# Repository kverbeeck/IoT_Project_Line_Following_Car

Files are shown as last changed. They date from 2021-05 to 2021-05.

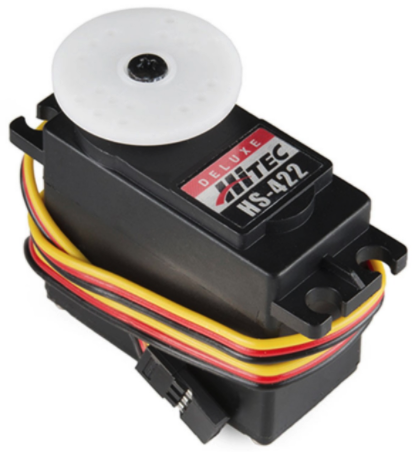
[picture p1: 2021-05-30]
Photos/New Design/Screen Shot 2021-05-30 at 12.21.13.png

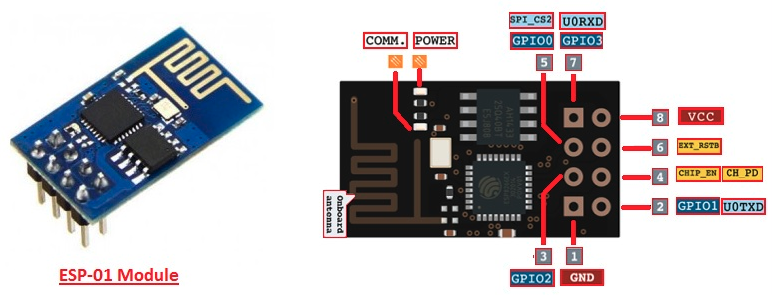
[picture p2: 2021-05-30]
Photos/New Design/Screen Shot 2021-05-30 at 12.37.02.png

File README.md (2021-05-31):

# IoT_Project_Self_Driving_Car

YouTube Video - Evaluation Week 5:  https://www.youtube.com/watch?v=Afq3bGS6EhM
YouTube Video - Evaluation Week 3: https://www.youtube.com/watch?v=AkNlcWbXoIE

## Description Assignment

Mercedes-Benz wants to automate its museum in Stuttgart. To do this, they want a system, which will allow a visitor to take a seat in a self-driving car. At the beginning of the tour, the visitor can take place in one of these cars that will drive around the entire museum. At the end, the visitor gets out and the trolley returns to the beginning of the tour so that new visitors can embark.

The route that the cars have to follow is fixed with a white tape on the floor, which makes it possible to adapt the tour if new exhibits are added. At each exhibit, a transverse white line will cross the tour line, this way the car knows where a museum piece is exhibited and that it has to stop. If the driver wants to continue, he or she can press a push-button inside the car and the tour will continue to the next exhibited item. 

To avoid congestion, the car will automatically continue the tour after 5 minutes.
Optionally, they also want to operate the cars remotely, for which the Control Center could take over the function of the push-button with an app.

Of course it is also important that the cars do not collide, therefore there should always be a minimum distance of 1.5 meters between the trolleys (Corona measures). If a car detects that it is too close to the one in front, it must stop and only continue if the one in front also continues to drive.

The cars are also equipped with LEDs. Using this signalization, the staff present in the control room can check cameras should there be a problem. 
•	A green LED will light up if there are no issues.
•	A red LED will light up if the car has lost track of the white line.
•	A orange LED will light up if the car detects an obstacle (other car or anything else in its path).

## Requirements:
•	The car can autonomously follow a track indicated by a white line.
•	The car must stop at a white line and can only continue driving if:
o	The driver pushes the drive-through push-button.
o	The trolley has been stationary for 5 minutes.
o	Optional: when the control center activates the car with their custom made application.
•	The cars must not collide.
o	If a car is halted, the cars behind it will keep their distance and only continue their route when the car in front of them continues its path.
•	Should there occurre problems with a car, it will be forced to stop and inform the control center by means of LEDs mounted on the cars.
o	Signalization in case of problems:
	Green LED: No issues.
	Orange LED: Obstacle (other car or anything else in its path).
	Red led: car has lost track of the white line.

## What does Mercedes-Benz expect
•	A brief description of the used hardware.
o	Files to produce the enclosure.
o	Electronic components.
o	Schematics and PCB (if applicable).
•	Documented code.
•	Brief description of to produce these cars themselves.
o	Tutorial.
All of this will be provided to them through a GitHub page.

## Follow-up:
Mercedes-Benz wants to take the cars into production after 7 weeks, there will be 3 evaluations.

In 3 weeks time the car should be driving and have basic functionality (line following). 

In 5 weeks they want to be sure that the cars have the correct functions to :
•	Follow the white line.
•	Stop and continue at each transverse white line.
•	Signalization.
In 7 weeks a working prototype should be presented. This prototype will be tested for functionality and speed. The prototype may not contain any loose components, so the use of a breadboard is not allowed. At this time, all documentation should also have been provided.

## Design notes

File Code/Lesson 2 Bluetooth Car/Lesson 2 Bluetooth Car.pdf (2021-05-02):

Http://www.elegoo.com

Tips: If you have any questions or run into any problems during assembling and testing Smart Robot Car please feel free to contact us at service@elegoo.com or euservice@elegoo.com (Europe customers).

# Lesson 2 Bluetooth Car

### Points of This Section

It is very important and so cool to control your car wirelessly in a certain space when we learn the Arduino. So in this lesson, we will teach you how to control a car by Bluetooth. Learning Objectives:

Learn how to use the Bluetooth module and the Bluetooth APP Learn how to control the light by using Bluetooth
Learn how to control the vehicle via Bluetooth

Preparations:
A vehicle (equipped with battery)
A USB cable
A Bluetooth module
A Phone or tablet

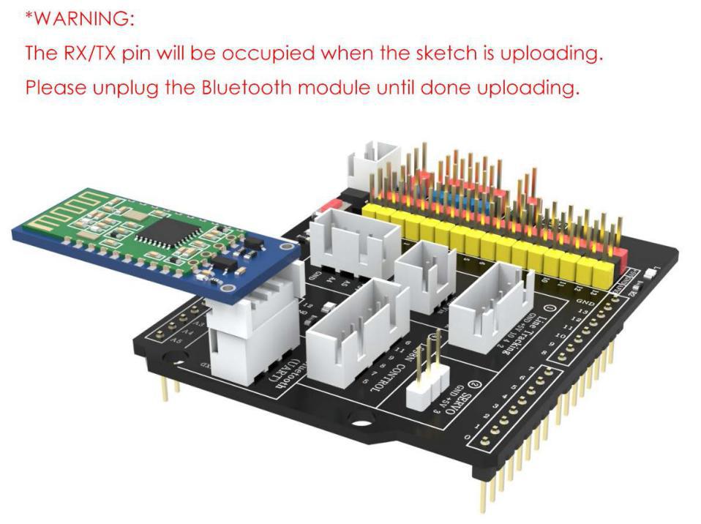
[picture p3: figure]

Tips: If you have any questions or run into any problems during assembling and testing Smart Robot Car please feel free to contact us at service@elegoo.com or euservice@elegoo.com (Europe customers).

# Ⅰ. Bluetooth module (BT16 4.2)

The Bluetooth is a wireless technology standard for exchanging data between fixed and mobile devices over short distances using short-wave UHF radio waves in the industrial, scientific, and medical radio bands (2.400 to 2.485 GHz), and building personal area networks (PANs). There are also RF protocols such as ZigBee and Wi-Fi.

In Smart Car Kit, we use the Bluetooth module model "DX-BT16", it can send serial data to other devices via Bluetooth.

DX-BT16 communicates with UNO through the RX/TX pin on the shield.

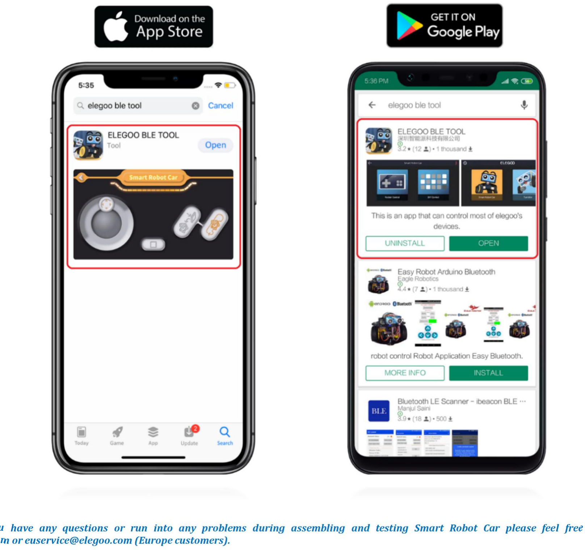
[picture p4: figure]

Tips: If you have any questions or run into any problems during assembling and testing Smart Robot Car please feel free to contact us at service@elegoo.com or euservice@elegoo.com (Europe customers).

## Ⅱ. Getting Started with the ELEGOO BLE Tool APP

Before beginning, connect the DX-BT16 4.2 Bluetooth module to the expansion board and turn on the

## power. STEP1: Install the application

For Android
There are two ways to install the Android application. 1. For Android system, copy the APK file to the Android products devices and install it. The APK file located in "Elegoo Smart Robot Car Kit V3.0_plus \ ELEGOO BLE Tool.apk" 2. Search “ELEGOO BLE Tool” in Google Play Store and install it. For IOS

Search “ELEGOO BLE Tool” in Apple APP Store and install it.

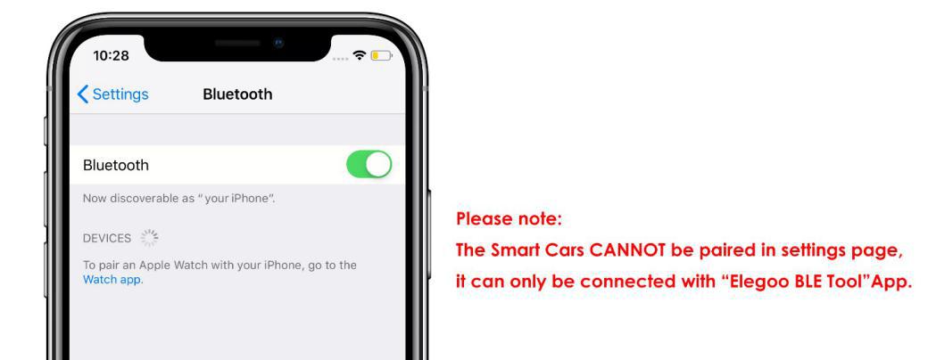
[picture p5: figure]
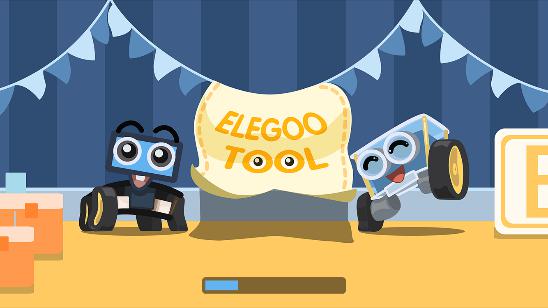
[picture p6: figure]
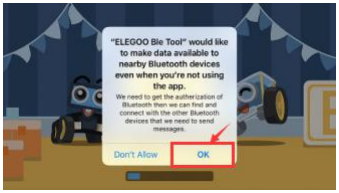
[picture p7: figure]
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

## STEP2: Open the APP

As below, we use an iPhone for example to show you how to control the Elegoo Smart Robot Car via this App:

First of all, turn on your cellphone’s Bluetooth function.

Open the “Elegoo BLE Tool” App.

Click OK (Please click OK when the App requests for the location permission, otherwise it will affect the Bluetooth function.)

## STEP3: Choose the language

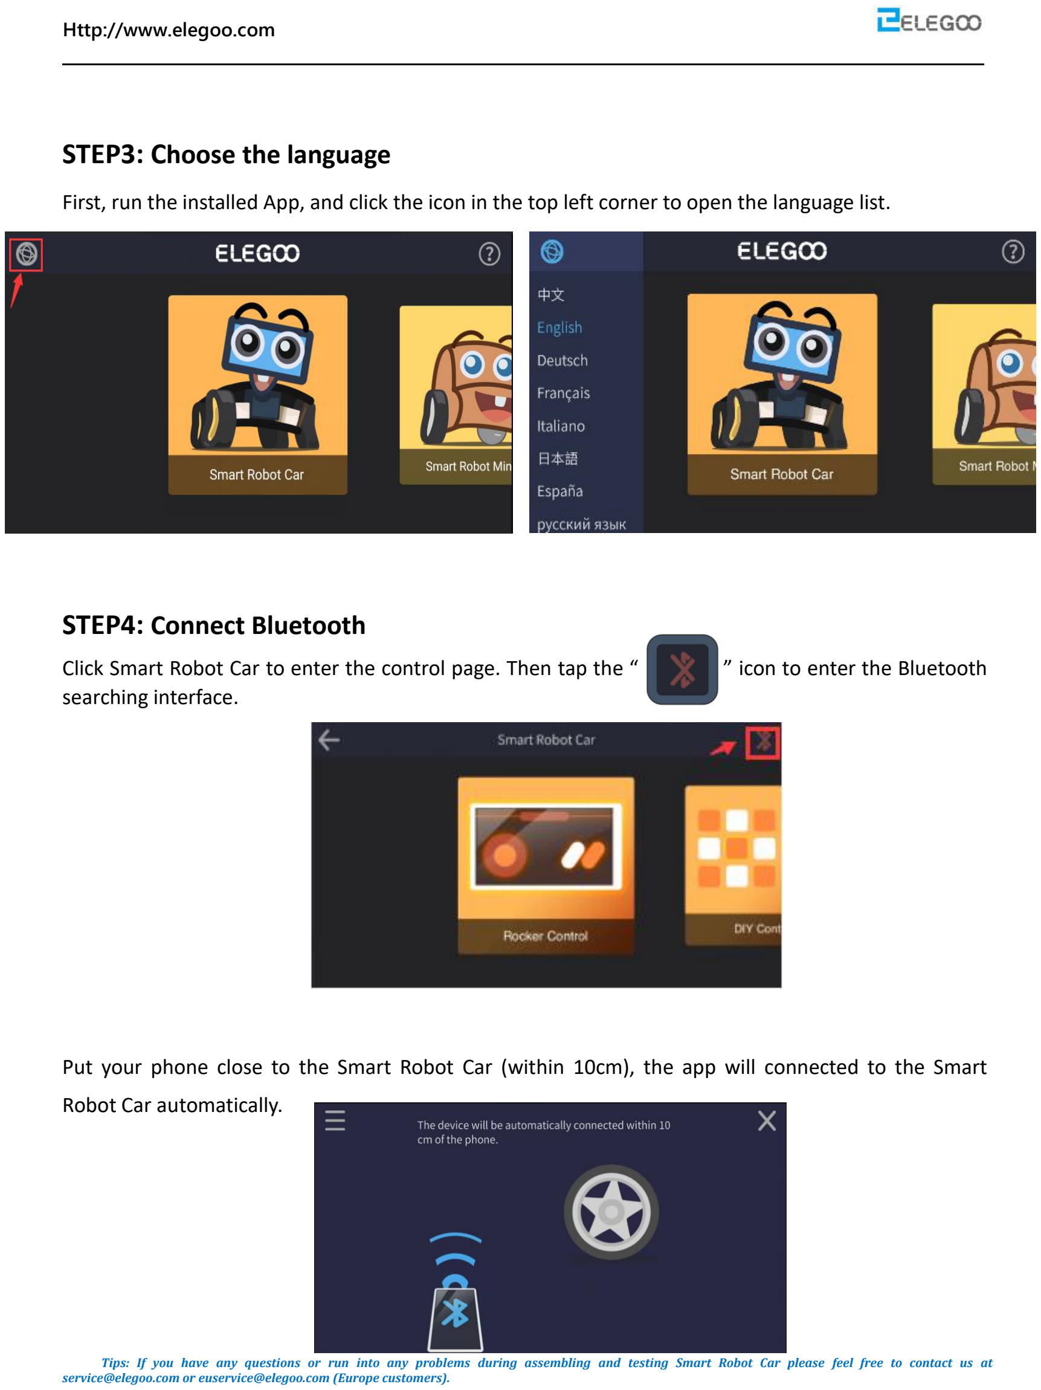
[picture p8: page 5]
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

First, run the installed App, and click the icon in the top left corner to open the language list.

## STEP4: Connect Bluetooth

Click Smart Robot Car to enter the control page. Then tap the “ ” icon to enter the Bluetooth searching interface.

Put your phone close to the Smart Robot Car (within 10cm), the app will connected to the Smart Robot Car automatically.

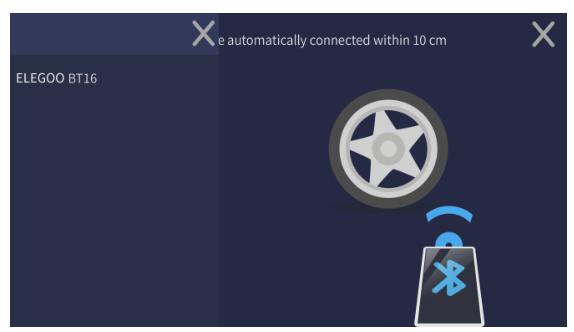
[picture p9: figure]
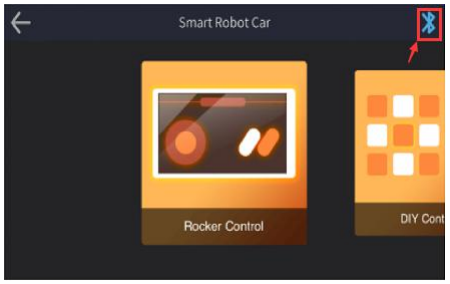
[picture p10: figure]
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

You can also open the Bluetooth device list by tapping the menu icon” “in the upper left corner and select “ELEGOO BT16” to connect the Smart Robot Car manually.

The Bluetooth status icon will turn blue when the Smart Robot Car is connected. Ⅲ. Control the light

Open the code file in the path “\Elegoo Smart Robot Car Kit V3.0 Plus\bluetooth_blink\blue tooth_blink.ino” and upload the program to the UNO board.

Disconnect it from the computer, and then switch on the car’s power supply. (TIPS: Please disconnect the Bluetooth when you upload the program, otherwise it will be failed to

upload the program.)

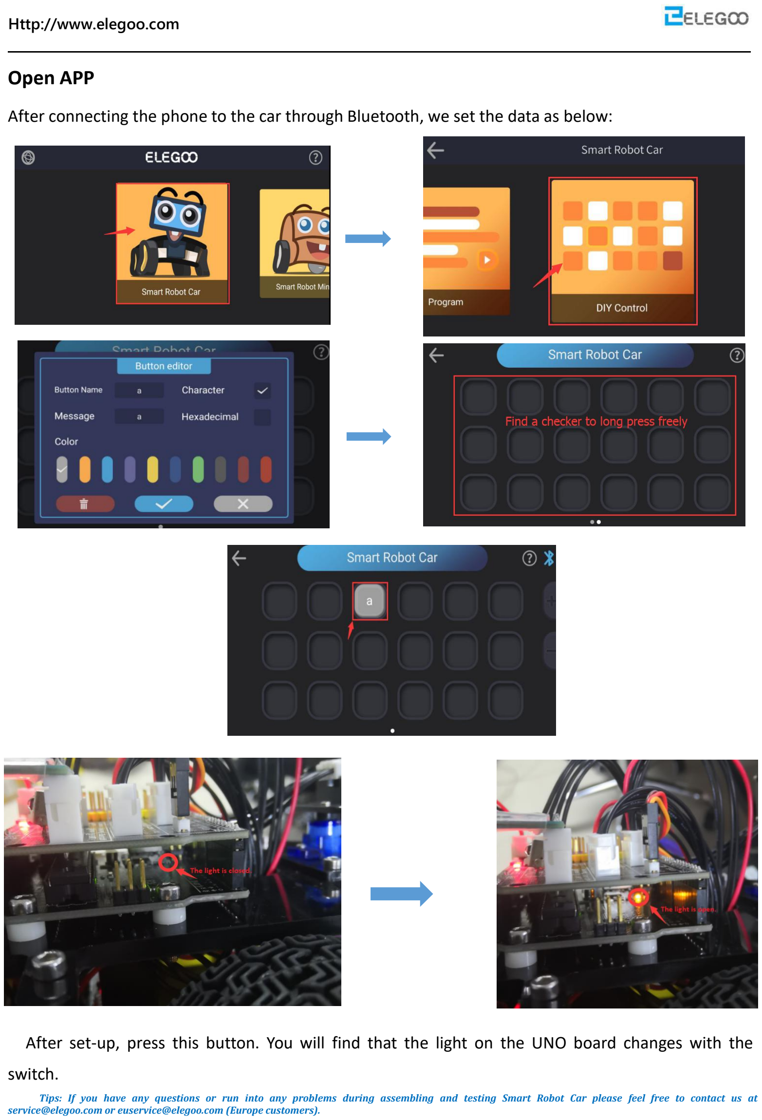
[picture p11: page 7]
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

### Open APP

After connecting the phone to the car through Bluetooth, we set the data as below:

After set-up, press this button. You will find that the light on the UNO board changes with the switch.

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

The code

Serial.begin(9600);
The purpose of this block of code is to set the baud rate of the UNO control board as 9600 and open the serial port. In this way, they can communicate with each other, because the original baud rate of the Bluetooth module is 9600. getstr = Serial.read(); //The Bluetooth serial port to receive the data in the function

if(getstr == 'a'){
stateChange();
}

This function is executed repeatedly within the circulating function. It will first read the data from the serial port and then check the data. If it meets the condition, it will execute the corresponding sub-function. For example, if it reads the letter ‘a’ from the serial port, it will execute the sub-function responsible for switching on/off the LED light. Ⅳ. Make a Bluetooth Car

When the car turns left or right, it’s not necessary to set the speed too fast. On the contrary, we need to control the speed of the car. But how to control?
The answer is PWM. PWM is the abbreviation of “Pulse Width Modulation”, is called pulse modulation in short, is an

effective technique to control analog circuit with digital output of microprocessor, car is used to change the speed of motor by altering duty cycle of a square wave. In other words, connect and break circuit between two sides of motor constantly is the switch of holding motor work, and motor will not be off when power is off because of the fast speed. So we can control the speed of car if we control specific value of power-on time and power-off time. The speed of car will be maximum when circuit is holding still. The speed of car will be minimum if circuit is holding off. The speed of car will be median in half time. PWM is a technology to get analog quantity through digital method. A square wave is formed by digital control, there are only two states: on and off. (That is high-low of digital pins). Simulate voltage changing from 0 to 5V by controlling specific value of duration on and off time. Occupied time of on (That is high level in academy) is called pulse width, so PWM is also called pulse

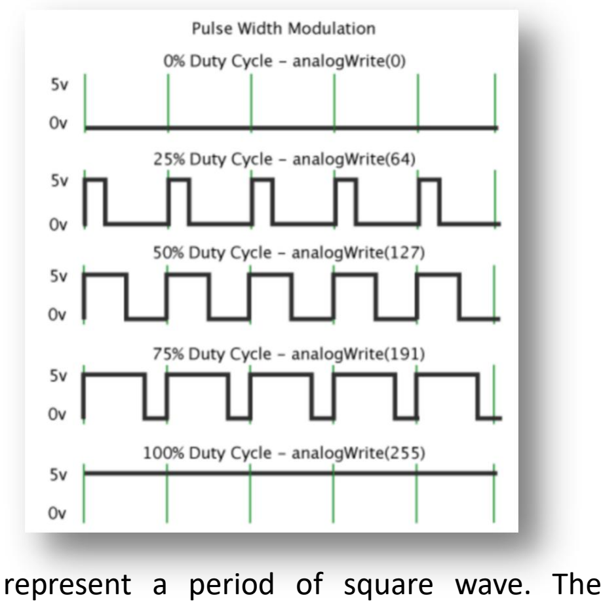
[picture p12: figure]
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

width modulation. Let’s learn about PWM through five square waves below.

Green vertical line above represent a period of square wave. The value written into every analogWrite(pin,value) corresponds to the percentage, the percentage is also called Duty Cycle, refer to the percentage gotten from specific value between duration high level and low level time in a period. In the above figure, from top to bottom, the first square wave, duty cycle is 0%, corresponding value is 0. Output circuit current is minimum, motor hold still. The longer duration time is, the bigger circuit current motor gets, the faster the speed is. So, the final one’s duty cycle is 100%, corresponding value is 255, motor rotates in full speed. 50% is medium hyponastic rotate speed, 25% is relatively slower, even can’t start. (The circuit current is relatively big to start motor because of static friction) PWM is mostly used to adjust light of LED and rotate speed of motor, wheel speed controlled by motor is easily be controlled. The advantage of PWM can be more reflected when you play with some Arduino cars. analogWrite(pin, value)；

analogWrite() is used to write analog value of 0 to 255 for PWM ports. What you need to note is that, analogWrite() is only used to digital pins with function of PWM. Pins with function of PWM in UNO are

only digital pins 3，5，6，9，10 and 11. Our car’s speed is controlled by connecting pin5 and pin6 of ENA and ENB. The program below, have

set a digital function int carSpeed = 150;
The speed is controlled in below program, so you can control the speed on your own.

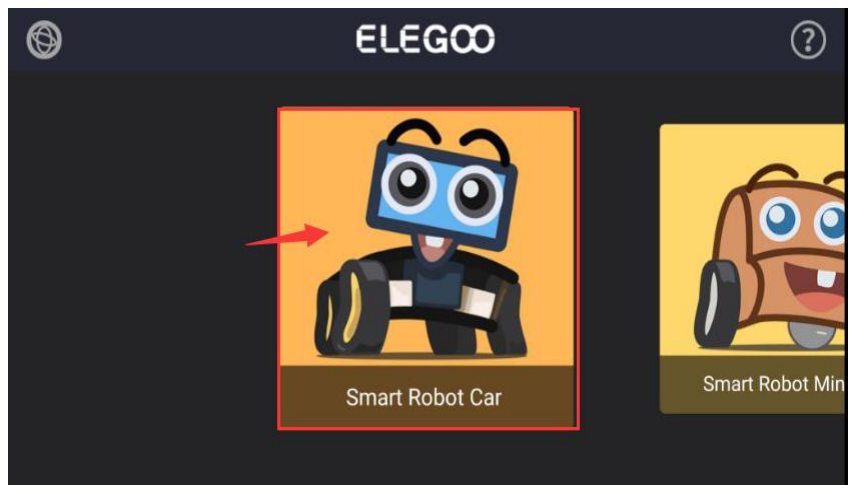
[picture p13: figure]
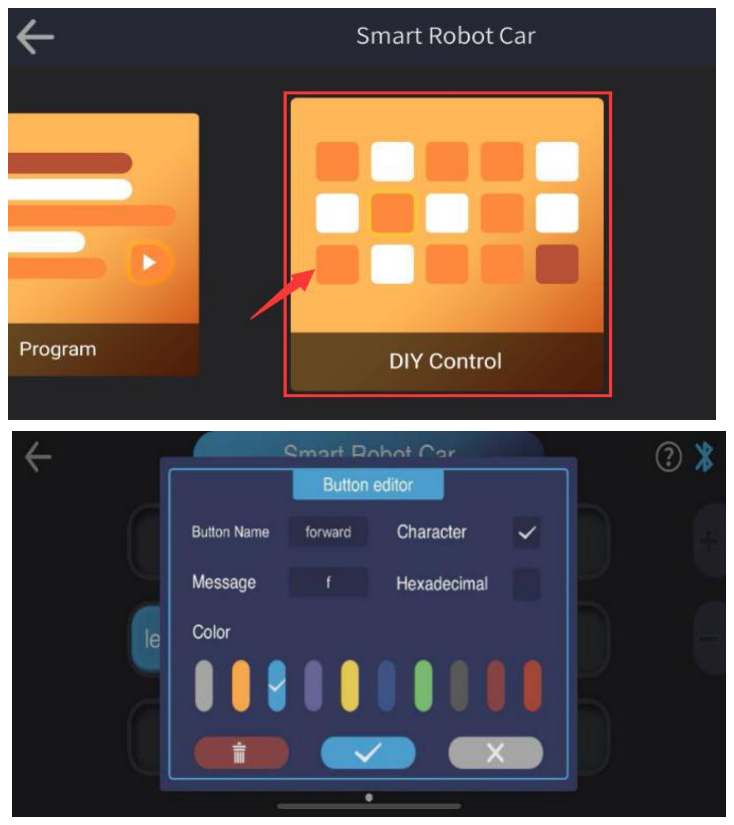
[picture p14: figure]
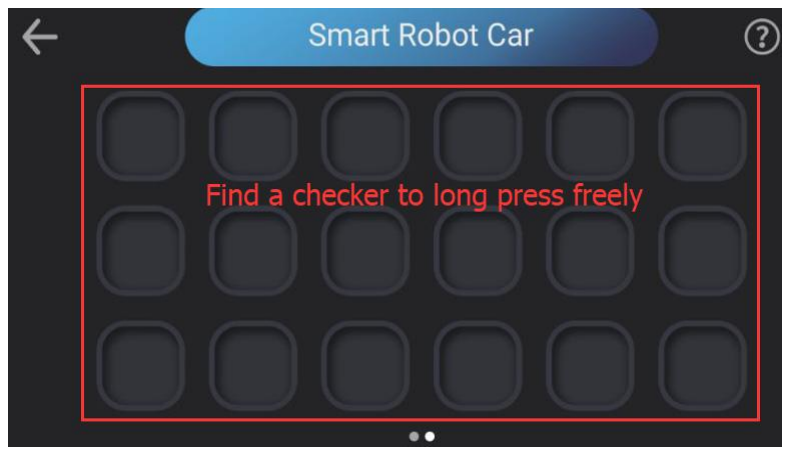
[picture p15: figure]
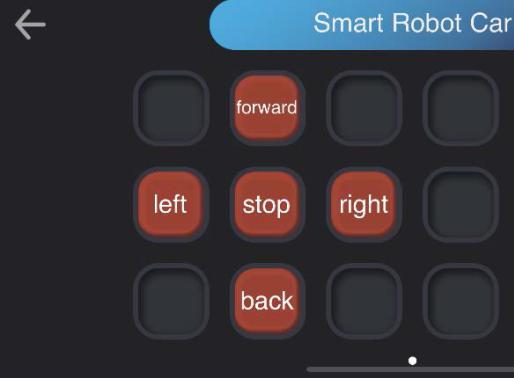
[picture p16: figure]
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

analogWrite(ENA, carSpeed);
analogWrite(ENB, carSpeed);

After learning the basic knowledge, we will upload the program as below to the car, open the code file in the path “\Elegoo Smart Robot Car Kit V3.0 Plus\bluetooth_car\ bluetooth_car.ino” and then upload the program to the UNO control board.

Switch on the power supply of the vehicle and put the car on the ground. Open the mobile APP, and set up parameters as follows.

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

Now we can control the car by Bluetooth and play with it.

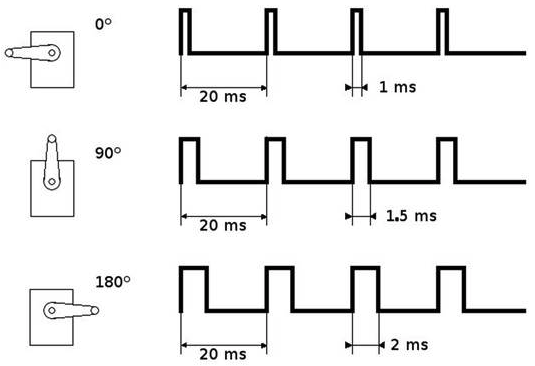
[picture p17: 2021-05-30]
Photos/New Design/Screen Shot 2021-05-30 at 12.24.56.png

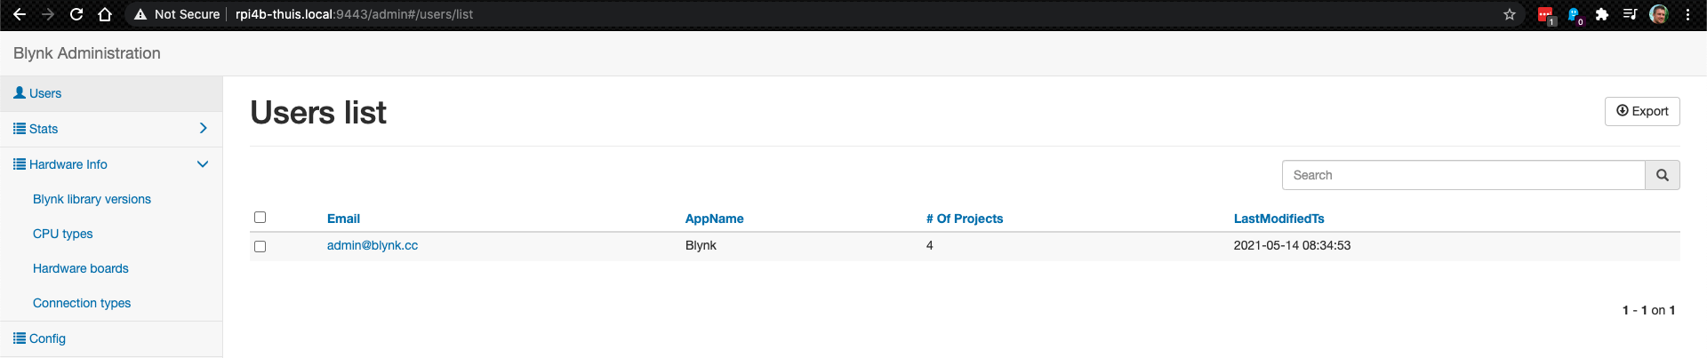
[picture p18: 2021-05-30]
Photos/New Design/Screen Shot 2021-05-30 at 11.56.59.png

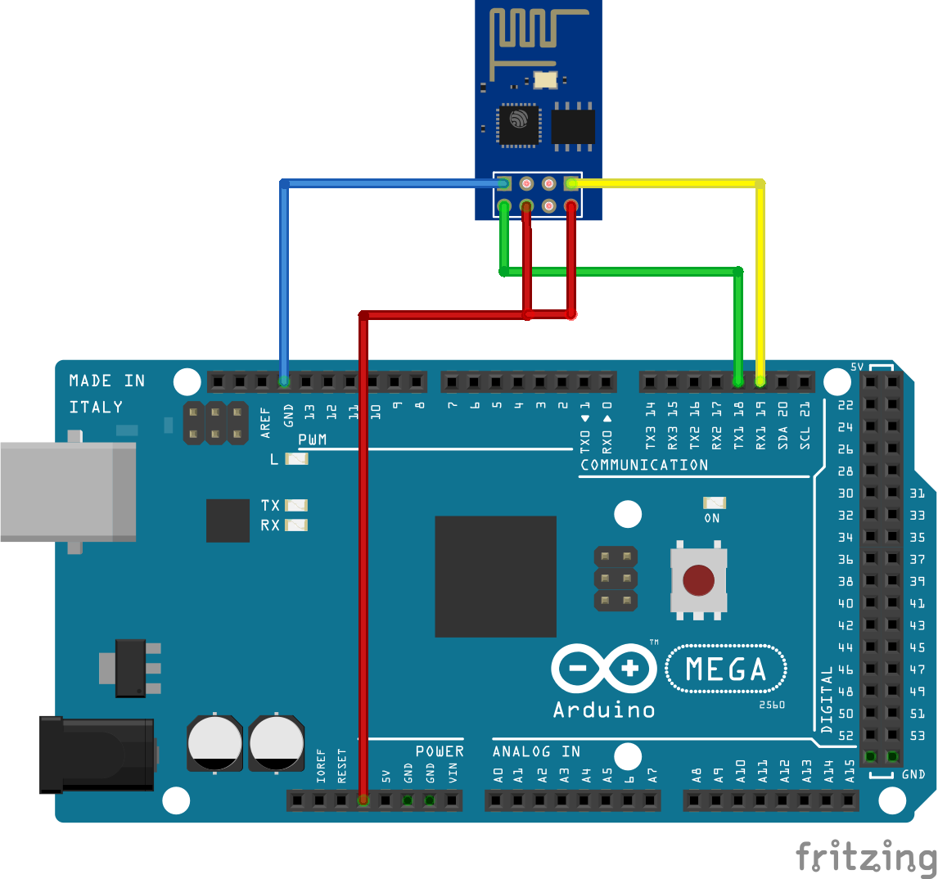
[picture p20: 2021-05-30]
Photos/New Design/ESP8266-ESP-01-op-Arduino-mega.png

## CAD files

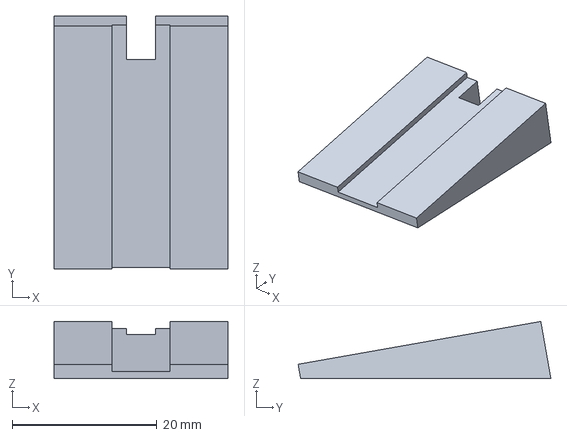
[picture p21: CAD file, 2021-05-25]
3D_Printing/CHEVY_SERVO_HOLDER_V3.3mf
24.0 x 34.9 x 7.88 mm

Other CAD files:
3D_Printing/CHEVY_SERVO_HOLDER V3.f3d
3D_Printing/CHEVY_SERVO_HOLDER V3.stl

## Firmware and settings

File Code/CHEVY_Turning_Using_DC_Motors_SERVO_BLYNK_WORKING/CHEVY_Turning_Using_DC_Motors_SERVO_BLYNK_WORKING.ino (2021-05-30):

/*
   You will need all 4 control signals, even if you have only 1 DC motor right and 1 DC motor left !!!!

   Left Motor truth table
   ----------------------------------------------------------------------------
   ENA         IN1             IN2         Description
   LOW   Not Applicable   Not Applicable   Motor is off
   HIGH        LOW             LOW         Motor is stopped (brakes)
   HIGH        LOW             HIGH        Motor is on and turning forwards
   HIGH        HIGH            LOW         Motor is on and turning backwards
   HIGH        HIGH            HIGH        Motor is stopped (brakes)

   Right Motor truth table
   ----------------------------------------------------------------------------
   ENB         IN3             IN4         Description
   LOW   Not Applicable   Not Applicable   Motor is off
   HIGH        LOW             LOW         Motor is stopped (brakes)
   HIGH        LOW             HIGH        Motor is on and turning forwards
   HIGH        HIGH            LOW         Motor is on and turning backwards
   HIGH        HIGH            HIGH        Motor is stopped (brakes)

   OLED Screen 128x64 connected to MEGA2560: SDA (20); SCL (21)

   BIG NOTE*: BLYNK Server will interfere with the servo's response time, so try to avoid sending 
   data while driving !!!!!!!!!!!!!
*/

// BLYNK info in Serial Monitor (Comment this out to disable prints and save space.
// #define BLYNK_PRINT Serial

/*
   Include the necessary libraries
*/
#include <Wire.h> // I2C Library
// Core graphics library for all Adafruit displays, providing a common set of graphics primitives (points, lines, circles, etc.).
#include <Adafruit_GFX.h>
#include <Adafruit_SSD1306.h> // Library for Adafruit Monochrome OLEDs based on SSD1306 drivers.
// The fonts that work better with the OLED display are the 9 and 12 points size.
#include <Fonts/FreeSerifBoldItalic12pt7b.h>
#include <Servo.h> // Servo library
#include <ESP8266_Lib.h> // Library for ESP-01 Wi-Fi Module
#include <BlynkSimpleShieldEsp8266.h> // Library for ESP-01 Wi-Fi Module talking to BLYNK Server

/*
   BLYNK Server
*/
char server[] = "192.168.10.122";
#define port 8080

// You should get Auth Token in the Blynk App.
// Go to the Project Settings (nut icon).
char auth[] = "SYbg29M3AiMlp83wB2HOlAhRHZ6wc1w_";

// Your WiFi credentials.
// Set password to "" for open networks.
char ssid[] = "BLYNK"; // Use the Orange modem Wi-Fi
char pass[] = "Bucky196";


// Hardware Serial on Mega, Leonardo, Micro...
#define EspSerial Serial1

// or Software Serial on Uno, Nano...
#include <SoftwareSerial.h>
//SoftwareSerial EspSerial(2, 3); // RX, TX

// Your ESP8266 baud rate:
#define ESP8266_BAUD 115200

ESP8266 wifi(&EspSerial);

BlynkTimer timer;

// This function sends Arduino's up time every second to Virtual Pin (5).
// In the app, Widget's reading frequency should be set to PUSH. This means
// that you define how often to send data to Blynk App.
void myTimerEvent()
{
  // You can send any value at any time.
  // Please don't send more that 10 values per second !!!!!!!!!
  Blynk.virtualWrite(V5, millis() / 1000);
}

/*
   128x64 OLED Screen
*/
#define SCREEN_WIDTH 128 // OLED display width, in pixels
#define SCREEN_HEIGHT 64 // OLED display height, in pixels

// Declaration for an SSD1306 display connected to I2C (SDA, SCL pins)
#define OLED_RESET -1 // Reset pin # (or -1 if sharing Arduino reset pin)
Adafruit_SSD1306 display(SCREEN_WIDTH, SCREEN_HEIGHT, &Wire, OLED_RESET);

/*
   SERVO Motor: HS-422 (20Kg)
*/
int servoPin = 3; // Port to control the servo Motor
// Start position of the Servo, stright wheels (only executed at begining)
int servoStartPos = 85;
int servoCenterPos = 85; // Drive Forward
int servoLeftmax = 110; // Turn Left // 105
int servoRightmax = 60; // Turn Right // 65

Servo myServo; // Create a virtual object into your Arduino so you can interact with it.
// Also give it a name (myServo).

/*
   LEDs
*/
#define redLED 34 // red LED on top of car (signalisation)
#define yellowLED 32 // yellow LED on top of car (signalisation)
#define greenLED 30 // green LED on top of car (signalisation)
#define LED_LF 22 // LED Left Front
#define LED_RF 24 // LED Right Front
#define LED_LB 50 // LED Left Back
#define LED_RB 52 // LED Right Back

// Red LED On
void RedLEDsOn(){
  digitalWrite(redLED, HIGH), digitalWrite(yellowLED, LOW), digitalWrite(greenLED, LOW);
}

// Yellow LED On
void YellowLEDsOn(){
  digitalWrite(redLED, LOW), digitalWrite(yellowLED, HIGH), digitalWrite(greenLED, LOW);
}

// Green LED On
void GreenLEDsOn(){
  digitalWrite(redLED, LOW), digitalWrite(yellowLED, LOW), digitalWrite(greenLED, HIGH);
}

/*
   Push-Button
*/
#define pushButton 44
int museum_timer;

/*
   Line Tracking Sensor
*/
#define LT_L 2 // Left Sensor
#define LT_M 4 // Middle Sensor
#define LT_R 10 // Right Sensor
int linelost_timer = 0;

/*
   HC-SR04 Distance Sensor
*/
int trigPin = 26;    // Trigger
int echoPin = 28;    // Echo
// The pingTravelDistance devided by 2 (/2)
float cm;

// The total pingTravelTime (RTT, two-way)
int pingTravelTime;

void measure_distance() {
  // The sensor is triggered by a HIGH pulse of 10 or more microseconds.

  // Give a short LOW pulse beforehand to ensure a clean HIGH pulse:
  digitalWrite(trigPin, LOW);
  // Delay to make sure that the triggerpin has been set to low.
  delayMicroseconds(5);
  // Read the signal from the sensor: a HIGH pulse whose
  // duration is the time (in microseconds) from the sending
  // of the ping to the reception of its echo off of an object.
  // (RTT, two-way)
  digitalWrite(trigPin, HIGH);
  delayMicroseconds(10);
  digitalWrite(trigPin, LOW);
  pingTravelTime = pulseIn(echoPin, HIGH);

  // Convert the time into a distance
  // distance = (traveltime/2) x speed of sound
  // We need to divide the traveltime by 2 because we have to take into account that the wave was sent,
  // hit the object, and is then returned back to the sensor.
  // The speed of sound is: 343m/s = 0.0343 cm/uS = 1/29.1 cm/uS
  // Divide by 29.1 or multiply by 0.0343 (Speed of sound)
  cm = (pingTravelTime / 2.) / 29.1;
}

/*
   DC Motors - L298N I/O Pins
*/
int ENA = 5;  // Control Channel A for left wheel
int ENB = 6;  // Control Channel B for right wheel
int IN1 = 7;  // Control Signal 1 for left wheel
int IN2 = 8;  // Control Signal 2 for left wheel
int IN3 = 9;  // Control Signal 3 for right wheel
int IN4 = 11; // Control Signal 4 for right wheel

// set car speed
int CAR_SPEED_F = 90; // Car Speed for Driving Forward 255 is Max. , Min. is 70.
int CAR_SPEED_T = 120; // Car Speed for Turning 255 is Max. , Min. is 70.

void stop_car() {
  digitalWrite(IN1, LOW); // IN1 = 0
  digitalWrite(IN2, LOW); // IN2 = 0
  digitalWrite(IN3, LOW); // IN3 = 0
  digitalWrite(IN4, LOW); // IN4 = 0
}

void forward(int car_speed) {
  analogWrite(ENA, car_speed);
  analogWrite(ENB, car_speed);
  digitalWrite(IN1, HIGH); // IN1 = 1
  digitalWrite(IN2, LOW); // IN2 = 0
  digitalWrite(IN3, LOW); // IN3 = 0
  digitalWrite(IN4, HIGH); // IN4 = 1
}

void turnLeft(int car_speed) {
  analogWrite(ENA, car_speed);
  analogWrite(ENB, car_speed);
  digitalWrite(IN1, LOW); // IN1 = 0
  digitalWrite(IN2, HIGH); // IN2 = 1
  digitalWrite(IN3, LOW); // IN3 = 0
  digitalWrite(IN4, HIGH); // IN4 = 1
}

void turnRight(int car_speed) {
  analogWrite(ENA, car_speed);
  analogWrite(ENB, car_speed);
  digitalWrite(IN1, HIGH); // IN1 = 1
  digitalWrite(IN2, LOW); // IN2 = 0
  digitalWrite(IN3, HIGH); // IN3 = 1
  digitalWrite(IN4, LOW); // IN4 = 0
}

/*
   128x64 OLED Screen
*/
void OLED_okdrive() {
  display.clearDisplay();
  // Display the measured distance on the OLED
  display.setCursor(0, 0);
  // Display static text
  display.println("Distance:");
  display.print(cm);
  display.println("cm");
  display.setCursor(0, 45);
  display.println("OK, DRIVE");
  display.display();
}

void OLED_stopcar() {
  display.clearDisplay();
  // Display the measured distance on the OLED
  display.setCursor(0, 0);
  // Display static text
  display.println("Distance:");
  display.print(cm);
  display.println("cm");
  display.setCursor(0, 45);
  display.println("STOP CAR !");
  display.display();
}

// Function while halting at an exhibit.
void OLED_sightseeing() {
  display.clearDisplay();
  // Display the measured distance on the OLED
  display.setCursor(0, 0);
  // Display static text
  display.println("Exhibit");
  display.setCursor(0, 30);
  display.println("Time Left:");
  display.print(museum_timer/1000);
  display.println(" Sec.");
  display.display();
}

//----------------------------------------------------------------------------------------------------

void setup() {
  
  // Debug console Serial Monitor
  Serial.begin(115200);

  /*
   BLYNK Server
  */
  
  // Set ESP8266 baud rate
  EspSerial.begin(ESP8266_BAUD);
  delay(10);

  // You can also specify server:
  // Blynk.begin(auth, wifi, ssid, pass, "blynk-cloud.com", 80);
  // Own Server and port
  Blynk.begin(auth, wifi, ssid, pass, server, port);

  // Setup a function to be called every second
  timer.setInterval(1000L, myTimerEvent);

  /*
    128x64 OLED Screen
  */

  // SSD1306_SWITCHCAPVCC = generate display voltage from 3.3V internally
  // 0x3C is I2C address
  if (!display.begin(SSD1306_SWITCHCAPVCC, 0x3C)) {
    Serial.println(F("SSD1306 allocation failed"));
    for (;;); // Don't proceed, loop forever
  }

  // Clear the buffer.
  display.clearDisplay();
  // display.setTextSize(1);
  display.setFont(&FreeSerifBoldItalic12pt7b);
  display.setTextColor(WHITE);
  display.invertDisplay(true);
  display.setCursor(20, 40);
  // Display static text (CHEVY WELCOME SCREEN)
  display.println("CHEVY");
  display.display();
  delay(1000);
  // Prepare the Display for dynamic text
  display.setFont();
  display.setTextSize(2);
  display.invertDisplay(false);
  delay(1000);

  /*
    SERVO Motor
  */
  // Attach the virtual Servo (object) to your Arduino using the control pin to interact with it.
  myServo.attach(servoPin);
  // The Servo will start at the configured Start position of the Servo.
  myServo.write(servoStartPos);

  /*
    Line Tracking Sensor
  */
  pinMode(LT_L, INPUT);
  pinMode(LT_M, INPUT);
  pinMode(LT_R, INPUT);

  /*
    LEDs
  */
  pinMode(redLED, OUTPUT);
  pinMode(yellowLED, OUTPUT);
  pinMode(greenLED, OUTPUT);
  pinMode(LED_LF, OUTPUT);
  pinMode(LED_RF, OUTPUT);
  pinMode(LED_LB, OUTPUT);
  pinMode(LED_RB, OUTPUT);
  digitalWrite(LED_LF, HIGH);
  digitalWrite(LED_RF, HIGH);
  digitalWrite(LED_LB, HIGH);
  digitalWrite(LED_RB, HIGH);

  /*
   Push-Button
  */
  pinMode(pushButton, INPUT);

  /*
    DC Motors
  */
  pinMode(ENA, OUTPUT);
  pinMode(ENB, OUTPUT);
  pinMode(IN1, OUTPUT);
  pinMode(IN2, OUTPUT);
  pinMode(IN3, OUTPUT);
  pinMode(IN4, OUTPUT);

  /*
     HC-SR04 Distance Sensor
  */
  pinMode(trigPin, OUTPUT);
  pinMode(echoPin, INPUT);
}

//----------------------------------------------------------------------------------------------------

void loop() {

  /*
   BLYNK Server
  */
  Blynk.run(); // Maintain the connection and send & receive data
  timer.run(); // Initiates BlynkTimer

  /*
     Line Tracking Sensor
  */

  // Print Line Tracking Sensor State: 0 is Black Line, 1 is no Black Line

  Serial.print("LT_L: ");
  Serial.print(digitalRead(LT_L));
  Serial.print("  LT_M: ");
  Serial.print(digitalRead(LT_M));
  Serial.print("  LT_R: ");
  Serial.println(digitalRead(LT_R));

  // If no Black Line is detected by Left (LT-L) or Right (LT-R) sensor.
  if (digitalRead(LT_L) && digitalRead(LT_R)) { // Drive Forward
    forward(CAR_SPEED_F);
    myServo.write(servoCenterPos);
    GreenLEDsOn();
    linelost_timer += 1;
    Serial.println(linelost_timer);
    if (linelost_timer >= 50) {
      stop_car();
      RedLEDsOn();
    }
  }

  // If a Black Line is detected by the Left Sensor.
  else if (!(digitalRead(LT_L)) && digitalRead(LT_R)) { // Turn Left
    turnLeft(CAR_SPEED_T);
    myServo.write(servoLeftmax);
    GreenLEDsOn();
    linelost_timer = 0;
    Serial.println(linelost_timer);
  }

  // If a Black Line is detected by the Right Sensor.
  else if (digitalRead(LT_L) && !(digitalRead(LT_R))) { // Turn Right
    turnRight(CAR_SPEED_T);
    myServo.write(servoRightmax);
    GreenLEDsOn();
    linelost_timer = 0;
    Serial.println(linelost_timer);
  }

  // If black perpendicular line is detected
  // Halt Car for 20 seconds, unless hardware or Virtual (BLYNK) push-button is pushed
  else if (!(digitalRead(LT_L)) && !(digitalRead(LT_M)) && !(digitalRead(LT_R))) { 
    YellowLEDsOn();
    delay(500); // Wait 500ms before halting the car
    myServo.write(servoCenterPos);
    stop_car();
    museum_timer = 20000; // Halt Car for 10 seconds
    linelost_timer = 0;
    Serial.println(linelost_timer);
    while (museum_timer >= 0){
      museum_timer -= 200; // subtract 200ms from timer
      OLED_sightseeing();
      delay(200); // delay 200ms after subtrackting from timer
      measure_distance(); // Not needed while halting for sight seeing
      Blynk.run(); // Otherwise BLYNK will crash while in the loop
      timer.run(); // Otherwise BLYNK will crash while in the loop
      if (digitalRead(pushButton) == 1){
        break;
      }
    }
  }

  measure_distance();

  // While the distance to the object is smaller or equal to 20, then STOP the CAR !!!
  while (cm < 20.0) {
    OLED_stopcar();
    stop_car();
    YellowLEDsOn();
    measure_distance();
    Blynk.run(); // Otherwise BLYNK will crash while in the loop
    timer.run(); // Otherwise BLYNK will crash while in the loop
  }

  OLED_okdrive();
}

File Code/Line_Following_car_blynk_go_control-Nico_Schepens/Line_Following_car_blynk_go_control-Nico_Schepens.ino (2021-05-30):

#include <analogWrite.h>

#define BLYNK_PRINT Serial
#include <WiFi.h>
#include <WiFiClient.h>
#include <BlynkSimpleEsp32.h>

// You should get Auth Token in the Blynk App.
// Go to the Project Settings (nut icon).
char auth[] = "hFiGeSS2SYIYC9vdREbCGmg6zG-OInC3";

// Your WiFi credentials.
// Set password to "" for open networks.
char ssid[] = "telenet-32924";
char pass[] = "";


// IR SENSOREN

int IRSensor_Binnen_Links = 26;
int IRSensor_Binnen_Rechts = 25;

//MOTOR LINKS
int in1 = 27;
int in2 = 14;


//MOTOR RECHTS
int in3 = 12;
int in4 = 13;

//LEDS
int led_rood = 4;
int led_geel = 2;
int led_groen = 15;

//TIMER
int counter = 0;



void setup() {
  Serial.begin(115200);

  /*
   * Wi-Fi
   */
  // Connect to Wi-Fi
  Serial.print("Connecting to ");
  Serial.println(ssid);
  WiFi.begin(ssid, pass);
  int wifi_ctr = 0;
  while (WiFi.status() != WL_CONNECTED) {
    delay(500);
    Serial.print(".");
  }
  Serial.println("WiFi connected");
  
  /*
   * BLYNK
   */
  // Initialize the BLYNK Client
  Blynk.begin(auth, ssid, pass, "server.wyns.it", 8081);
  

  pinMode(IRSensor_Binnen_Links, INPUT);
  pinMode(IRSensor_Binnen_Rechts, INPUT);
  pinMode(in1, OUTPUT);
  pinMode(in2, OUTPUT);
  pinMode(in3, OUTPUT);
  pinMode(in4, OUTPUT);
  pinMode(led_rood, OUTPUT);
  pinMode(led_geel, OUTPUT);
  pinMode(led_groen, OUTPUT);
}

void loop() {

  Blynk.run();

  Serial.print("IRSensor Binnen Rechts status = " );
  Serial.println(digitalRead(IRSensor_Binnen_Rechts));
  Serial.print("IRSensor Binnen Links status = " );
  Serial.println(digitalRead(IRSensor_Binnen_Links));



  //VOORUIT
  if (digitalRead(IRSensor_Binnen_Rechts) == 1 && digitalRead(IRSensor_Binnen_Links) == 1) {
    digitalWrite(in1, 200);
    digitalWrite(in2, 0);
    digitalWrite(in3, 0);
    digitalWrite(in4, 200);
    digitalWrite(led_groen, HIGH);
    digitalWrite(led_geel, LOW);
    counter = counter + 1;
    Serial.print(counter);

    if (counter >= 200) {
      digitalWrite(in1, 0);
      digitalWrite(in2, 0);
      digitalWrite(in3, 0);
      digitalWrite(in4, 0);
      digitalWrite(led_groen, LOW);
      digitalWrite(led_geel, LOW);
      digitalWrite(led_rood, HIGH);
    }

  }

  //STOP
  if (digitalRead(IRSensor_Binnen_Rechts) == 0 && digitalRead(IRSensor_Binnen_Links) == 0) {
    digitalWrite(in1, 0);
    digitalWrite(in2, 0);
    digitalWrite(in3, 0);
    digitalWrite(in4, 0);
    digitalWrite(led_groen, LOW);
    digitalWrite(led_geel, HIGH);
    digitalWrite(led_rood, LOW);
    counter = 0;



  }

  //DRAAIEN
  if (digitalRead(IRSensor_Binnen_Links) == 0 && digitalRead(IRSensor_Binnen_Rechts) == 1) {
    digitalWrite(in1, 0);
    digitalWrite(in2, 200);
    digitalWrite(in3, 0);
    digitalWrite(in4, 200);
    digitalWrite(led_groen, HIGH);
    digitalWrite(led_geel, LOW);
    digitalWrite(led_rood, LOW);
    counter = 0;

  }

  if (digitalRead(IRSensor_Binnen_Links) == 1 && digitalRead(IRSensor_Binnen_Rechts) == 0) {
    digitalWrite(in1, 200);
    digitalWrite(in2, 0);
    digitalWrite(in3, 200);
    digitalWrite(in4, 0);
    digitalWrite(led_groen, HIGH);
    digitalWrite(led_geel, LOW);
    digitalWrite(led_rood, LOW);
    counter = 0;

  }
}
